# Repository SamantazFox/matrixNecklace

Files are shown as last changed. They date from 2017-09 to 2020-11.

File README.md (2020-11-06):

# matrixNecklace

Index
-----

* [Introduction](#introduction)
* [Project's Description](#projects-description)
* [Folders](#folders)
* [Known Issues](#known-issues)
* [To Do](#to-do)

Introduction
------------

This project is a simple customizable necklace, based on an AtTiny2313a (or
alternatively an ATtiny48/88) and a 8x8 dot LED matrix.

The very first idea came from furrtek's mind, called **jewelmatrix**. You can
find his project on [his website](http://furrtek.free.fr/?a=jewelmatrix)
(french).

The idea behind this project was to improve Furrtek's project and add a few
options, such as a rechargeable Li-Ion battery (instead of a coin cell) and a
cross-platform tool to add custom patterns on the fly, without the need to
rebuild and flash the ATtiny every time.

Implemented features :
	* Fully customizable patterns
	* Rechargeable by USB

Planned features :
    * Easy on-the-fly programmation by any device running **\*nix**,
    **windows**, **MacOS** or **android** operating system, using the device's
    screen as the transmission support
    * USB connection to host device (faster than screen transmision)

Project's Description
-------------------

* matrixEditor
    - matrixEditor is the UI for matrixNecklace's patterns creation.
    - Based on the FLTK graphic library.
    - Still at experimental level.

* matrixNecklace
    - One of the following microntrollers:
        * An ATtiny2313/2313a/4313: easy soldering solution
        * An ATtiny48/88: if you feel adventurous to solder QFN32 :P
    - 8x8 dot LED matrix
    - Li-Ion battery, which can be recharged via micro USB type B

Folders
-------

* **/doc**
    - Sphinx documentation
    - Datasheets

* **/editor**
    - C++ Cross-platform editor source code
    - Compile script and instructions

* **/firmware**
    - AVR hardware source code
    - Compile script and instructions
    - Basic patterns (for reference)
    - Arduino sketch used to determine matrixes' pinout

* **/hardware**
    - **/hardware/schematic**
        - KiCad librarties
        - KiCad schematic/pcb files
        - Bill of material

* **/licenses**
    - Project's license file(s)
    - Every libraries used's specific license file(s)

Known Issues
------------

* 50/60 Hz differences may cause problems for screen transmission upload

To Do
-----

* Documentation
    - Sphinx documentation
    - Compiling HowTo

* Editor
    - Patterns import/export
    - Patterns ordering and timings
    - Integrated compiler (and it's output)
    - Device uploader

* Firmware
    - Correct pinout/registers match
    - Update for AtTiny48/88
    - Create custom bootloader
    - Add USB support

* Hardware
    - Finish pinout
    - Finish chips libraries
    - Release schematics
    - Create BOM
    - Still AtTiny2313a version ?
    - Mini USB type B version ?

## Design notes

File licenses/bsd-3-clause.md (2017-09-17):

Copyright <YEAR> <COPYRIGHT HOLDER>

Redistribution and use in source and binary forms, with or without
modification, are permitted provided that the following conditions are met:

1. Redistributions of source code must retain the above copyright notice, this
   list of conditions and the following disclaimer.

2. Redistributions in binary form must reproduce the above copyright notice,
   this list of conditions and the following disclaimer in the documentation
   and/or other materials provided with the distribution.

3. Neither the name of the copyright holder nor the names of its contributors
   may be used to endorse or promote products derived from this software without
   specific prior written permission.

THIS SOFTWARE IS PROVIDED BY THE COPYRIGHT HOLDERS AND CONTRIBUTORS "AS IS"
AND ANY EXPRESS OR IMPLIED WARRANTIES, INCLUDING, BUT NOT LIMITED TO, THE
IMPLIED WARRANTIES OF MERCHANTABILITY AND FITNESS FOR A PARTICULAR PURPOSE ARE
DISCLAIMED. IN NO EVENT SHALL THE COPYRIGHT HOLDER OR CONTRIBUTORS BE LIABLE
FOR ANY DIRECT, INDIRECT, INCIDENTAL, SPECIAL, EXEMPLARY, OR CONSEQUENTIAL
DAMAGES (INCLUDING, BUT NOT LIMITED TO, PROCUREMENT OF SUBSTITUTE GOODS OR
SERVICES; LOSS OF USE, DATA, OR PROFITS; OR BUSINESS INTERRUPTION) HOWEVER
CAUSED AND ON ANY THEORY OF LIABILITY, WHETHER IN CONTRACT, STRICT LIABILITY,
OR TORT (INCLUDING NEGLIGENCE OR OTHERWISE) ARISING IN ANY WAY OUT OF THE USE
OF THIS SOFTWARE, EVEN IF ADVISED OF THE POSSIBILITY OF SUCH DAMAGE.

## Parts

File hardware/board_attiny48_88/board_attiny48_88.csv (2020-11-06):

Reference | Quantity | Value | Footprint | Datasheet
C1 C2 C3 | 3 | 10uF | Capacitor_SMD:C_0603_1608Metric_Pad1.05x0.95mm_HandSolder
D1 | 1 | Green | LED_SMD:LED_0603_1608Metric_Pad1.05x0.95mm_HandSolder
D2 | 1 | Red | LED_SMD:LED_0603_1608Metric_Pad1.05x0.95mm_HandSolder
J1 | 1 | USB | Connector_USB:USB_Micro-B_Molex_47346-0001
J2 | 1 | VBAT | Connector_Wire:SolderWirePad_1x01_SMD_1x2mm | ~
J3 | 1 | GND | Connector_Wire:SolderWirePad_1x01_SMD_1x2mm | ~
Led1 | 1 | 788ASR_A | led_matrix:ASR788
R1 R2 R4 R5 | 4 | 1K | Resistor_SMD:R_0603_1608Metric_Pad1.05x0.95mm_HandSolder
R3 | 1 | 5K | Resistor_SMD:R_0603_1608Metric_Pad1.05x0.95mm_HandSolder
SW1 | 1 | SW_SPDT | Buttons_Switches_SMD:SW_SPDT_PCM12
U1 | 1 | ATtiny48-MU | Package_DFN_QFN:QFN-32-1EP_5x5mm_P0.5mm_EP3.1x3.1mm | http://ww1.microchip.com/downloads/en/DeviceDoc/doc8008.pdf
U2 | 1 | TP4056 | Package_SO:Diodes_SO-8EP | https://dlnmh9ip6v2uc.cloudfront.net/datasheets/Prototyping/TP4056.pdf

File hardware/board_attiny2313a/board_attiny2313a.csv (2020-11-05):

Reference | Quantity | Value | Footprint | Datasheet
C1 C3 C2 | 3 | 10uF | Capacitor_SMD:C_0603_1608Metric_Pad1.05x0.95mm_HandSolder
D1 | 1 | Green | LED_SMD:LED_0603_1608Metric_Pad1.05x0.95mm_HandSolder
D2 | 1 | Red | LED_SMD:LED_0603_1608Metric_Pad1.05x0.95mm_HandSolder
J1 | 1 | USB | Connector_USB:USB_Micro-B_Molex_47346-0001
J2 | 1 | VBAT | Connector_Wire:SolderWirePad_1x01_SMD_1x2mm | ~
J3 | 1 | GND | Connector_Wire:SolderWirePad_1x01_SMD_1x2mm | ~
Led1 | 1 | 788ASR_A | led_matrix:ASR788
R2 R1 R4 R5 | 4 | 1K | Resistor_SMD:R_0603_1608Metric_Pad1.05x0.95mm_HandSolder
R3 | 1 | 5K | Resistor_SMD:R_0603_1608Metric_Pad1.05x0.95mm_HandSolder
SW1 | 1 | SW_SPDT | Buttons_Switches_SMD:SW_SPDT_PCM12
U1 | 1 | ATtiny2313A-SU | Package_SO:SOIC-20W_7.5x12.8mm_P1.27mm | http://ww1.microchip.com/downloads/en/DeviceDoc/doc8246.pdf
U2 | 1 | TP4056 | Package_SO:Diodes_SO-8EP | https://dlnmh9ip6v2uc.cloudfront.net/datasheets/Prototyping/TP4056.pdf

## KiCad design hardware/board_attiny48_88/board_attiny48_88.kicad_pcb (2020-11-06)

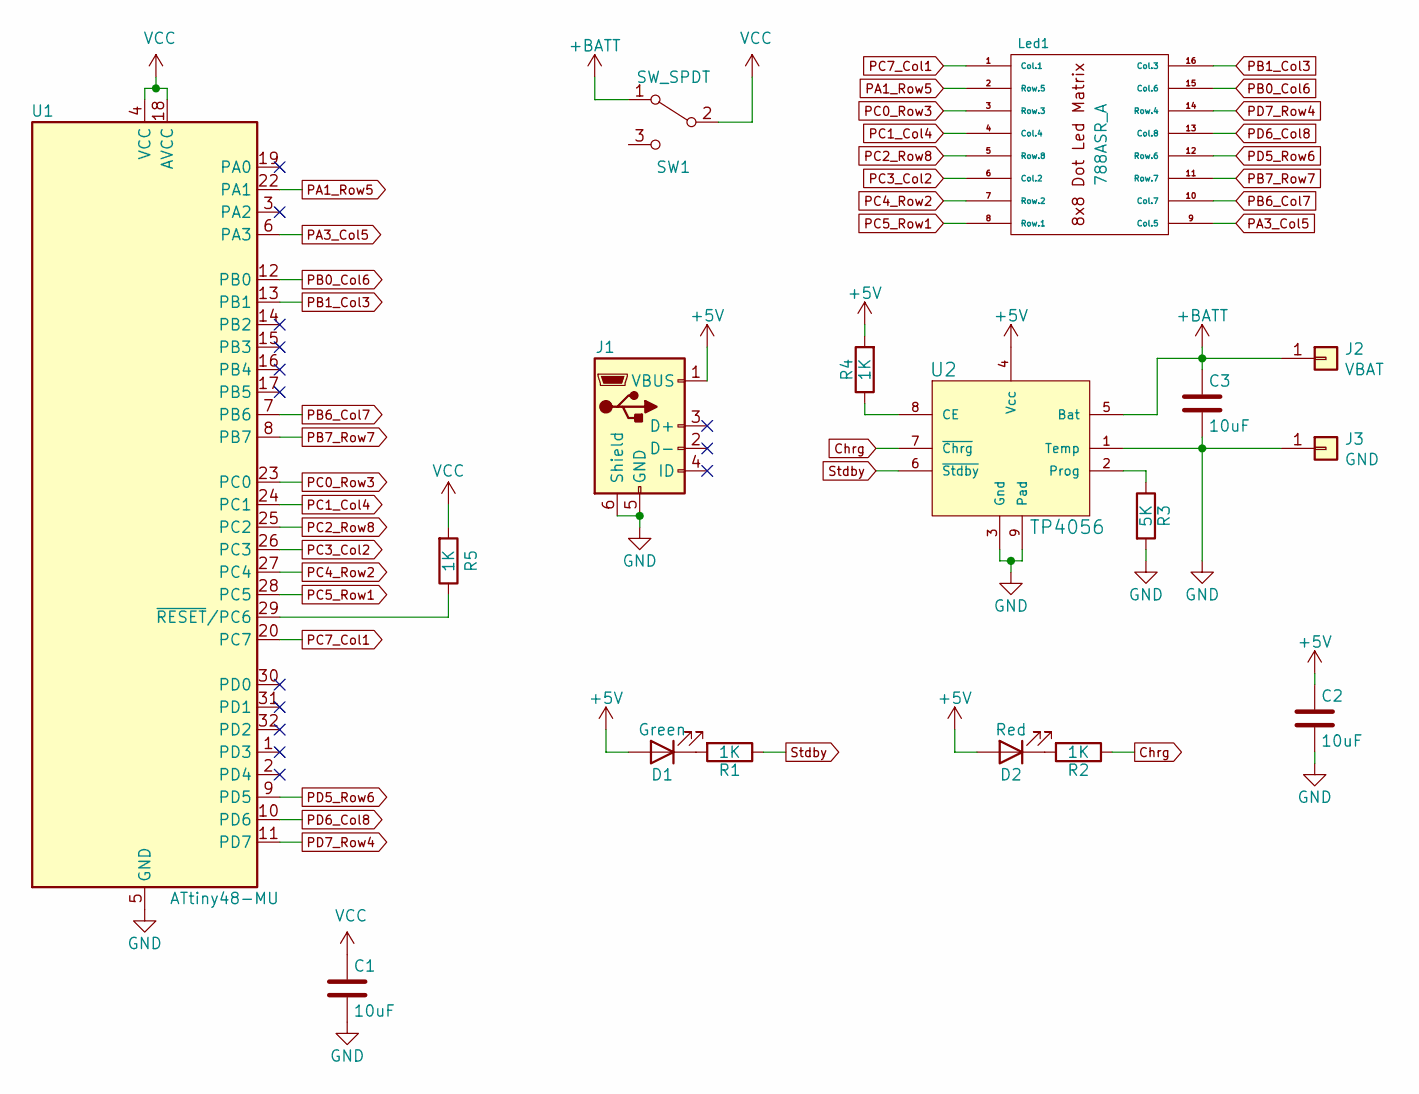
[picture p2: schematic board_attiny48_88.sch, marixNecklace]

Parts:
C1, C2, C3: 10uF; C_0603_1608Metric_Pad1.05x0.95mm_HandSolder
D1: Green; LED_0603_1608Metric_Pad1.05x0.95mm_HandSolder
D2: Red; LED_0603_1608Metric_Pad1.05x0.95mm_HandSolder
J1: USB; USB_Micro-B_Molex_47346-0001
J2: VBAT; SolderWirePad_1x01_SMD_1x2mm
J3: GND; SolderWirePad_1x01_SMD_1x2mm
Led1: 788ASR_A; ASR788
R1, R2, R4, R5: 1K; R_0603_1608Metric_Pad1.05x0.95mm_HandSolder
R3: 5K; R_0603_1608Metric_Pad1.05x0.95mm_HandSolder
SW1: SW_SPDT; SW_SPDT_PCM12
U1: ATtiny48-MU; QFN-32-1EP_5x5mm_P0.5mm_EP3.1x3.1mm
U2: TP4056; Diodes_SO-8EP

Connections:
+5V: C2.1, D1.2 (A), D2.2 (A), J1.1 (VBUS), R4.2, U2.4 (Vcc)
+BATT: C3.1, J2.1, SW1.1 (A), U2.5 (Bat)
Chrg: R2.1, U2.7 (~Chrg)
GND: C1.2, C2.2, C3.2, J1.5 (GND), J1.6 (Shield), J3.1, R3.2, U1.5 (GND), U1.21 (GND), U1.33 (GND), U2.1 (Temp), U2.3 (Gnd), U2.9 (Pad)
unnamed: D1.1 (K), R1.2
unnamed: D2.1 (K), R2.2
unnamed: R3.1, U2.2 (Prog)
unnamed: R4.1, U2.8 (CE)
unnamed: R5.1, U1.29 (~RESET~/PC6)
PA1_Row5: Led1.2 (Row.5), U1.22 (PA1)
PA3_Col5: Led1.9 (Col.5), U1.6 (PA3)
PB0_Col6: Led1.15 (Col.6), U1.12 (PB0)
PB1_Col3: Led1.16 (Col.3), U1.13 (PB1)
PB6_Col7: Led1.10 (Col.7), U1.7 (PB6)
PB7_Row7: Led1.11 (Row.7), U1.8 (PB7)
PC0_Row3: Led1.3 (Row.3), U1.23 (PC0)
PC1_Col4: Led1.4 (Col.4), U1.24 (PC1)
PC2_Row8: Led1.5 (Row.8), U1.25 (PC2)
PC3_Col2: Led1.6 (Col.2), U1.26 (PC3)
PC4_Row2: Led1.7 (Row.2), U1.27 (PC4)
PC5_Row1: Led1.8 (Row.1), U1.28 (PC5)
PC7_Col1: Led1.1 (Col.1), U1.20 (PC7)
PD5_Row6: Led1.12 (Row.6), U1.9 (PD5)
PD6_Col8: Led1.13 (Col.8), U1.10 (PD6)
PD7_Row4: Led1.14 (Row.4), U1.11 (PD7)
Stdby: R1.1, U2.6 (~Stdby)
VCC: C1.1, R5.2, SW1.2 (B), U1.4 (VCC), U1.18 (AVCC)

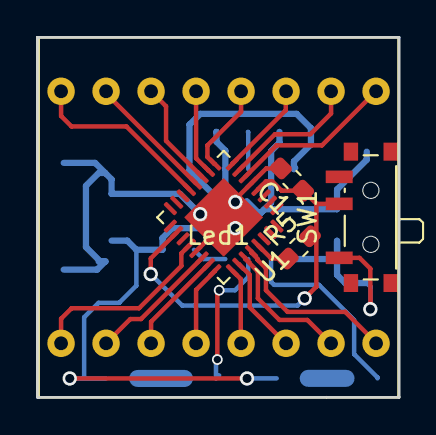
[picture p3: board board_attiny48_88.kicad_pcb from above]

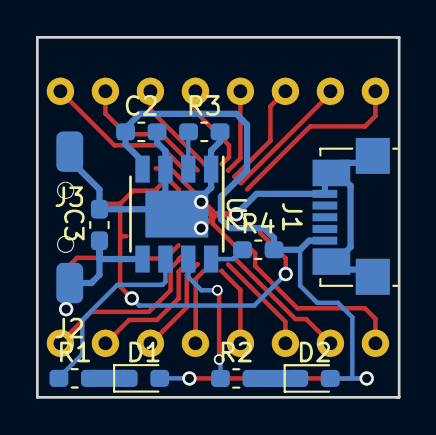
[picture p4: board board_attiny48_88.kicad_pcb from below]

Board: 2 copper layers, 20.1 x 20.0 mm, 17 parts (12 on the bottom side), 27 nets.

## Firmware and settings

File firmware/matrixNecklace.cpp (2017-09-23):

/* matrixNecklace.cpp
 *
 * Main program file
 *
 * Copyright 2015 - 2017 (C) Taz8du29
 * Refer to LICENSE.MD for more infos about copyright
*/



// Used fuse bits : Self Programming enabled, 8Mhz clock divided by 8
// -U lfuse:w:0x64:m -U hfuse:w:0xdf:m -U efuse:w:0xfe:m


/* INCLUDES */

// My small utility file
#include <myUtils.h>

// Functions who stores functions and data in flash.
#include <avr/pgmspace.h>

// Self Programing functions
// #include <avr/boot.h>

// My pattern file
#include "patterns.h"



/* CONSTANTS DEFINITIONS */

// Frames speed
#define speed1 ((uint16_t) 700)
#define speed2 ((uint16_t) 1000)

// Main definition of pins used
uint8_t rows[8][2] = {{PORTB,0}, {PORTB,5}, {PORTD,5}, {PORTD,0}, {PORTD,4}, {PORTD,1}, {PORTD,2}, {PORTB,4}};
uint8_t cols[8][2] = {{PORTA,1}, {PORTA,0}, {PORTB,1}, {PORTD,3}, {PORTB,2}, {PORTB,6}, {PORTB,7}, {PORTD,5}};

// Serial strings
PROGMEM const uint8_t initDone[] = "Initialisation done.\n\r";
PROGMEM const uint8_t scrFilld[] = "Screen filled !\n\r";
PROGMEM const uint8_t scrClear[] = "Screen cleared !\n\r";
PROGMEM const uint8_t writingP[] = "writing pattern : ";



/* MAIN FUNCTION DEFINITIONS */

// MySerial initialisation
// extern "C" void SendByte(uint8_t) {}
void serOut(const uint8_t* str) {while (*str) SendByte(*str++);}
void serOut_P(const uint8_t* str) {while (pgm_read_byte(*str)) SendByte(pgm_read_byte(*str++));}

// BasicSerial main function implementation
// void serOut(const uint8_t* str) { while (*str) TxByte(*str++); }
// void serOut_P(const uint8_t* str) { while (pgm_read_byte(*str)) TxByte(pgm_read_byte(*str++)); }

// Light all the matrix's LEDs
void fillScreen(void) {
	for(uint8_t i = 0; i < 8; i++) {
		sbi(rows[i][0], rows[i][1]);
		cbi(cols[i][0], cols[i][1]);
	}
	serOut_P(scrFilld);
}

// Shut off all the matrix's LEDs
/*
void clearScreen(void) {
	for(uint8_t i = 0; i < 8; i++) {
		cbi(rows[i][0], rows[i][1]);
		sbi(cols[i][0], cols[i][1]);
	}
	serOut_P(scrClear);
}
*/

// Write a specific number of times the desired pattern
// TODO : improve timings efficiency (and power ?)
void writePattern(const uint8_t pat[8], uint8_t frames) {
	for(uint8_t x = 0; x < frames; x++) {
		for(uint8_t i = 0; i < 8; i++) {
			sbi(rows[i][0], rows[i][1]);
			for(uint8_t j = 7; j >= 0; j--) {
				if(readBit(pgm_read_byte(pat[i]), j)) { cbi(cols[j][0], cols[j][1]); }
				sbi(cols[j][0], cols[j][1]);
			}
			cbi(rows[i][0], rows[i][1]);
		}
	}
}



/* MAIN PROGRAM */

int main(void) {
	// Define direction register
	DDRA = 0x03;
	DDRB = 0xFF;
	DDRD = 0x7F;

	// Start w/ a fresh new screen, and start debugging via serial
	//clearScreen();
	serOut_P(initDone);

	// uuuh ... that's not pretty clean :$
	while(1)
	{
		fillScreen();
		_delay_ms(5000);

		// Battery animation
		serOut_P(writingP);
		for(uint8_t x = 0; x < 15; x++) {
			writePattern(bat_0, speed1);
			writePattern(bat_20, speed1);
			writePattern(bat_40, speed1);
			writePattern(bat_60, speed1);
			writePattern(bat_80, speed1);
			writePattern(bat_100, speed1);
		}

		// Space Invaders 1 animation
		serOut_P(writingP);
		for(uint8_t x = 0; x < 20; x++) {
			writePattern(SI1_On, speed2);
			writePattern(SI1_Off, speed2);
		}

		// Space Invaders 2 animation
		serOut_P(writingP);
		for(uint8_t x = 0; x < 20; x++) {
			writePattern(SI2_On, speed2);
			writePattern(SI2_Off, speed2);
		}

		// Other stuff
		/*
		serOut_P(writingP);
		for(uint8_t x = 0; x < 10; x++) {
			writePattern(heart, speed2);
		}

		serOut_P(writingP);
		for(uint8_t x = 0; x < 10; x++) {
			writePattern(smile, speed2);
		}

		serOut_P(writingP);
		for(uint8_t x = 0; x < 10; x++) {
			writePattern(clock, speed2);
		}
		*/
	}
}

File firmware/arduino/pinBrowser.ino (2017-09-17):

/*
	     _______________
	13 -| 16          1 |- 9
	12 -| 15          2 |- 8
	A0 -| 14   8x8    3 |- 7
	A1 -| 13          4 |- 6
	A2 -| 12   LED    5 |- 5
	A3 -| 11  Matrix  6 |- 4
	A4 -| 10          7 |- 3
	A5 -|_9___________8_|- 2
*/

short pin[16] = {9, 8, 7, 6, 5, 4, 3, 2, A5, A4, A3, A2, A1, A0, 12, 13};

void waitForInput(uint8_t del = 500) {
	while(digitalRead(10) == HIGH) {}
	delay(del);
}


void setup() {
	Serial.begin(9600);

    for(uint8_t i = 0; i < 16; i++) {
		pinMode(pin[i], OUTPUT);
	}

	pinMode(10, INPUT);
	digitalWrite(10, HIGH);
}

void loop() {
	Serial.println("----- ROWS -----");

	for(uint8_t i = 0; i < 16; i++) {
		digitalWrite(pin[i], LOW);
	}

	for(uint8_t i = 0; i < 16; i++) {
		Serial.print("Pin : ");
		Serial.println(i);

		digitalWrite(pin[i], HIGH);
		waitForInput();
		digitalWrite(pin[i], LOW);
	}


	Serial.println("----- COLS -----");

	for(uint8_t i = 0; i < 16; i++) {
		digitalWrite(pin[i], HIGH);
	}

	for(uint8_t i = 0; i < 16; i++) {
		Serial.print("Pin : ");
		Serial.println(i);

		digitalWrite(pin[i], LOW);
		waitForInput();
		digitalWrite(pin[i], HIGH);
	}
}

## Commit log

2017-09-17 Moved arduino folder to firmware/
2017-09-23 Switched from short/char to uint8_t
    Removed useless code.
    Improved comments in firmware/Makefile.
    [matrixNecklace.cpp]
2017-12-08 Added matrixEditor part of the project Very basic version, just a matrix of stylized buttons.
2018-06-16 matrixEditor first source code release
    Just a very basic version: a matrix of stylized buttons.
2018-06-16 Reformatted ledMatrix architecture Leds are all child of ledMatrix and have a unique ID
    Separated menuEntries code in a separate cpp file
    In order to reduce matrix size, Leds graphics are now 48x48 px
    Also fixed a minor typo on matrixEditor.cpp's last #endif
2018-06-16 Moved class "Led" to it's own file
2018-06-16 Get Leds position offste from parent group
2018-06-16 'LedMatrix' and 'Menu' are now two independant classes
    'LedMatrix' creates and positions all its Led children on
    initialization.
    'Menu' class creates the menu and manages callbacks.
    Main window's children are now part of the 'Application' class.
2018-06-16 'Matrix' method to get all the leds states getData() returns as a uint64_t all the Lesd states, from left to right, and top to bottom.
2018-06-16 Fixed Led index caclculation A small calculation mistake mad the Leds being drawn by columns instead of lines (Led with index 7 ended at the bottom left instead of the top right)
    [matrix.cpp]
2018-06-16 Fixed the getData() and cd_save() functions
    The matrix element is passed to the getData() function, that means some
    re-ordering of the main header file has to be done in order to solve
    class linking issues :
    - Forward declaration of the project classes
    - Moved project files' #includes to the bottom of the header
    Also removed 'logs' global variable
    [matrix.cpp]
2018-06-16 Changed Led::invert method to a write function accepting arguments Needed for future use.
    [matrix.cpp]
2018-06-16 Added Matrix::setData and reworked Matrix::getData
    getData now uses 64-bits unsigned integer.
    setData takes also 64-bits unsigned integer.
    Hexadecimal parsing of raw data was moved to a private method of
    'Matrix', so it can be used by getData and setData as a verbose output
    to user.
    [matrix.cpp]
2018-06-16 Added a contant to 'Matrix' class for led count All related changes (mainly in "for" loops) were made, too.
    Fixed a missing "this->end()" at the end of Matrix's constructor.
    Added a fallback "return 0;" in Led's event handler.
    [matrix.cpp]
2018-06-16 Complete rework of the sizing system to include resizeability
    The window size can now be dynamically changed.
    For now, the matrix can't be resized because of buttons' images. So, the
    window is width-restrained.
    Also added a Pos (position) data structure to keep track of the elements
    offset during initialization.
    [matrix.cpp]
2018-06-16 Use `offset` variable for frame position/size
2018-06-16 Added the frame as a child of `Application`
    Plus some code re-ordering.
2018-06-16 Removed the tile encapsulaion of `LoggerField` as it is useless. The logs field still resizes, as it's part of the `frame` tile.
2020-11-02 Add KiCad libraries used for this board
2020-11-02 Add board schematics - ATtiny 2313a variant
    [board_attiny2313a.kicad_pcb, board_attiny2313a.sch]
2020-11-05 Add bill of materials (BOM)
    [board_attiny2313a.csv]
2020-11-05 Fix soldermask keepout zones being on the wrong layer
    [board_attiny2313a.kicad_pcb]
2020-11-06 Add board schematics - ATtiny 48/88 variant
    [board_attiny48_88.kicad_pcb, board_attiny48_88.sch]
2020-11-06 Add bill of materials (BOM) for ATtiny 48/88 variant
    [board_attiny48_88.csv]
2020-11-06 Add gerbers for ATtiny 2313a variant
    [board_attiny2313a-B_Cu.gbr, board_attiny2313a-B_Mask.gbr, board_attiny2313a-B_SilkS.gbr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]
2020-11-06 Add gerbers for ATtiny 48/88 variant
    [board_attiny48_88-B_Cu.gbr, board_attiny48_88-B_Mask.gbr, board_attiny48_88-B_SilkS.gbr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]
